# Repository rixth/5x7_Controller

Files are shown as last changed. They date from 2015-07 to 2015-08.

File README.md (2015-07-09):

# 5x7 Controller

This is a project that provides hardware & firmware for a small (43x70mm) board that contains four 5x7 row-anode LED matrices.

## Controller primary components

* 4 5x7 row-anode LED matrices
* 2 Texas Instruments TLC59284 sixteen-channel LED driver (constant-current sink)
* 1 CD4022B 8-output counter
* 1 74HC540 inverting buffer
* 7 IRLML5203 P-channel mosfets
* Freescale Kinetis MKL02Z32VFM4 Cortex M0+ MCU (32k flash)
* So. Many. Interfaces.

## Brief design overview

This display is drawn row-by-row. The row to be drawn is selected by the counter, which feeds it output through an inverting-buffer, then out to the P-channel mosfets. The columns are selected by the TLC59284 which are essentially shift registers that can sink considerable (configurable) current, so you can avoid having many current limiting resistors for the LEDs.

The Kinetis MCU will be responsible for drawing the display, and receiving commands from the main controller. I have exposed the MCU's i2c, SPI and UART lines to headers.

The raw inputs for the row/column selection have also been broken out to the left side of the board - 4 pins are required (shift clk, in, latch + counter clk). This can be reduced by 1 if a solder bridge is used to tie the clock of the counter to the latch of the shift register.

## Software overview

The software is still in the planning phases, but the rough plan is to use a slim RTOS like [AtomThreads](http://atomthreads.com/) to both keep the display refeshed and take input from the host controller over i2c, SPI or serial.

The MCU will have an ASCII character set preloaded - but the command set will also allow the host to toggle single LEDs, rows and columns.

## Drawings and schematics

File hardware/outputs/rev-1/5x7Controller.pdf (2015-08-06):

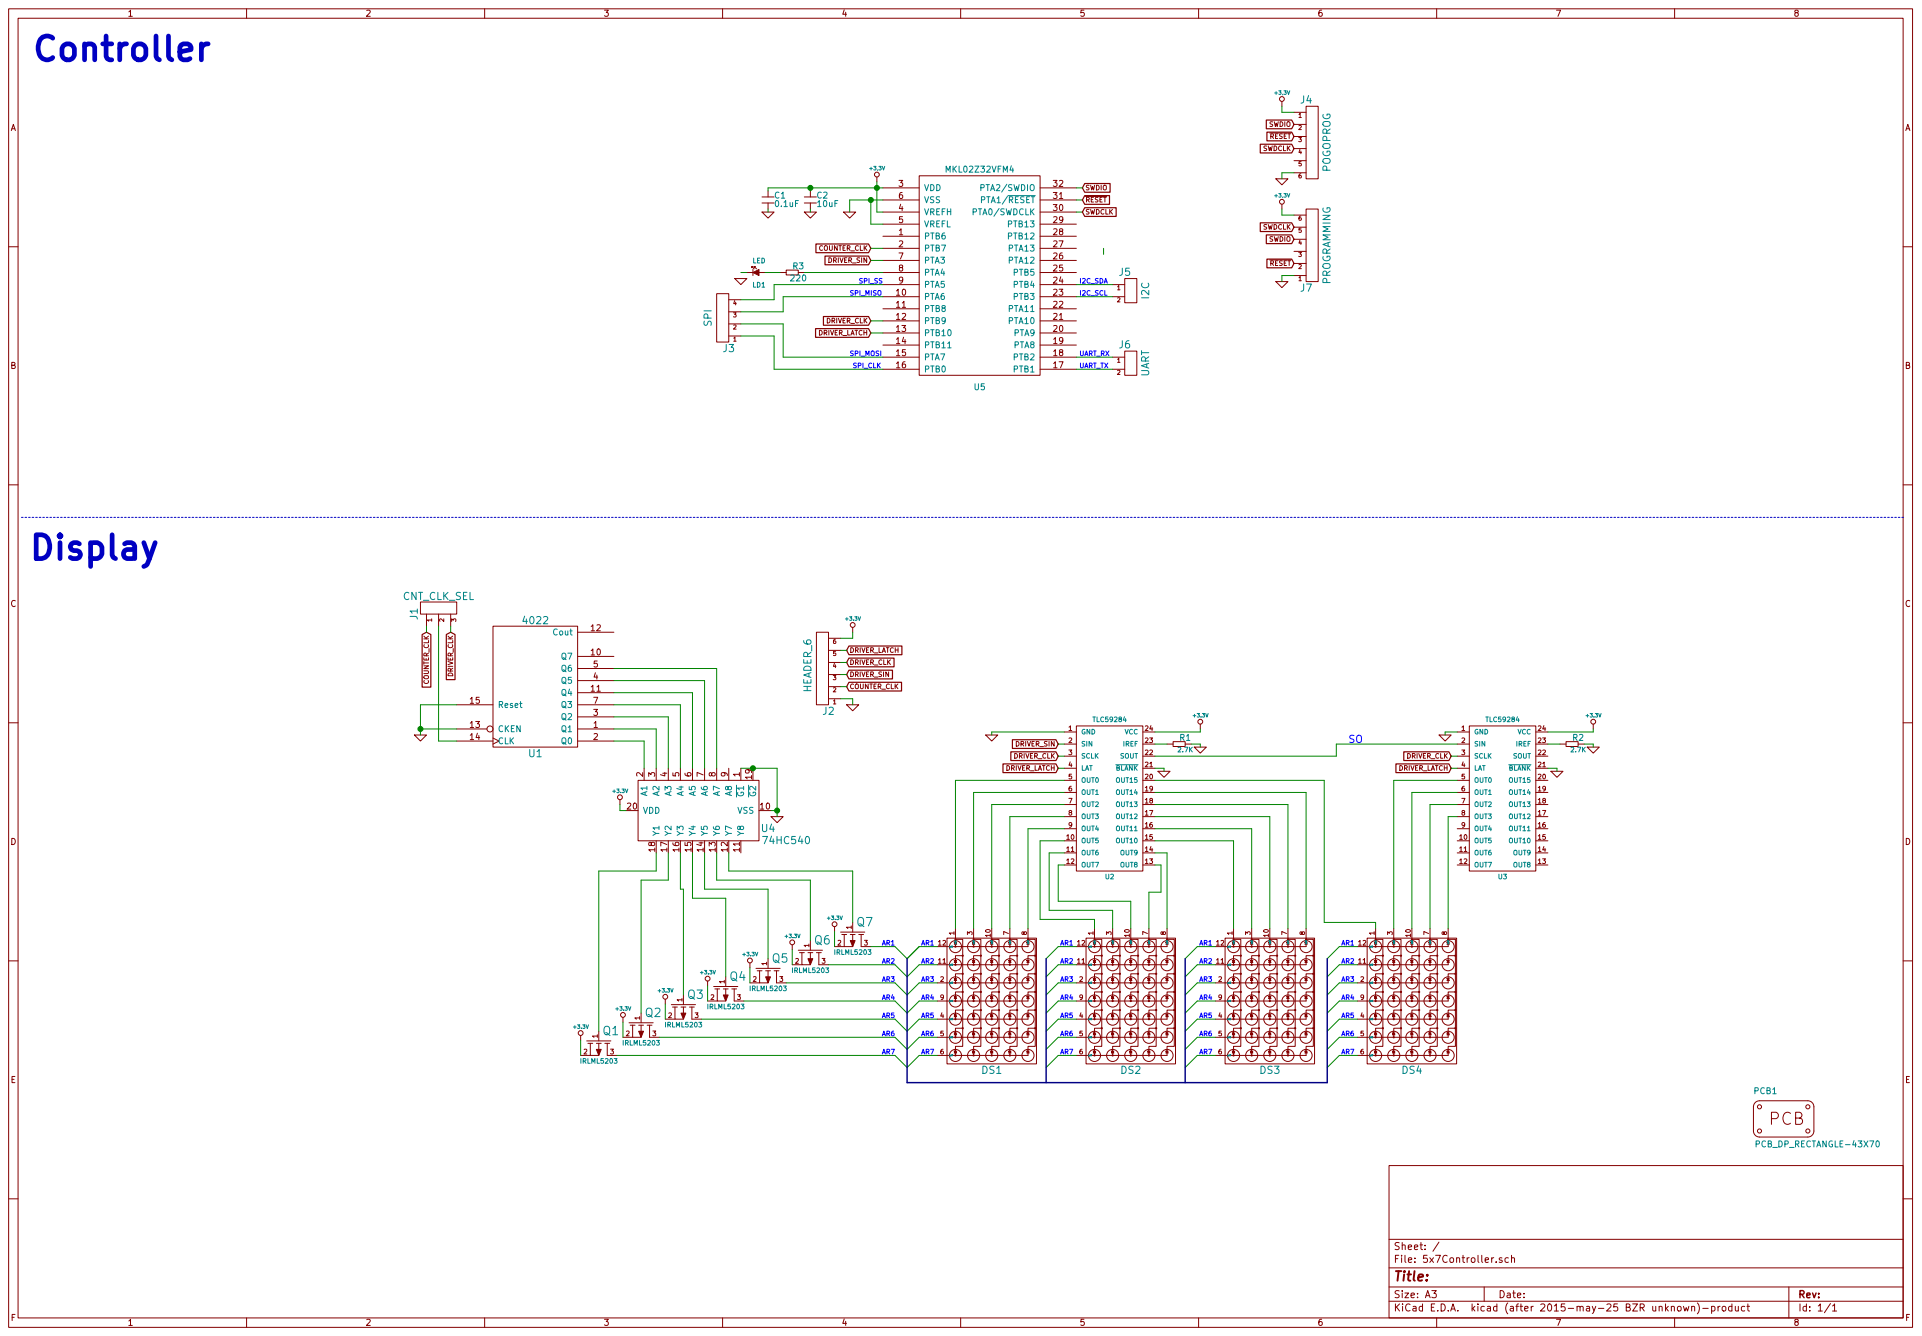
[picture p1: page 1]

Id: 1/1 Title: File: 5x7Controller.sch Sheet: / cc1 1

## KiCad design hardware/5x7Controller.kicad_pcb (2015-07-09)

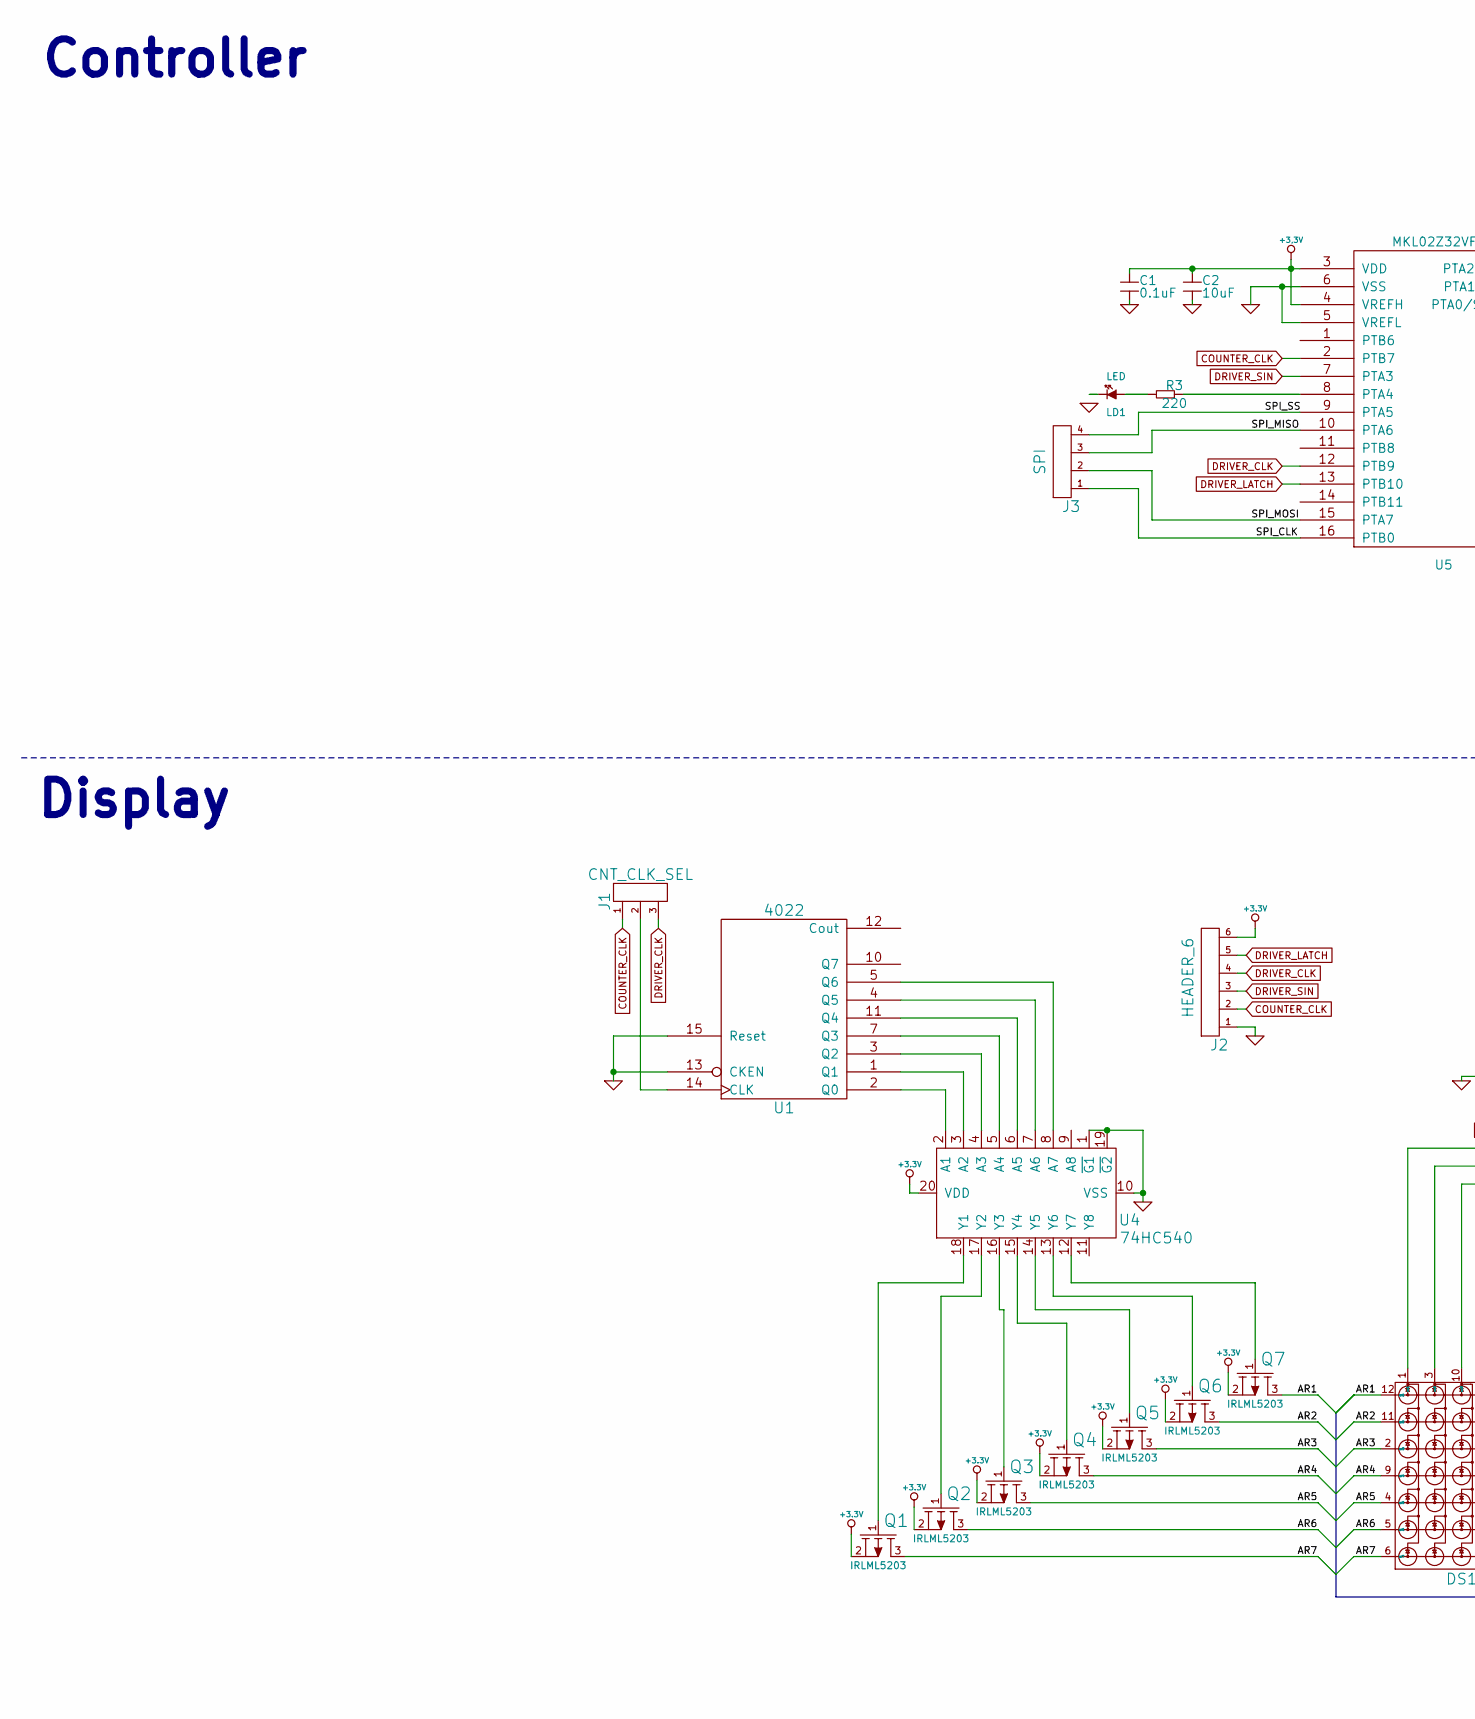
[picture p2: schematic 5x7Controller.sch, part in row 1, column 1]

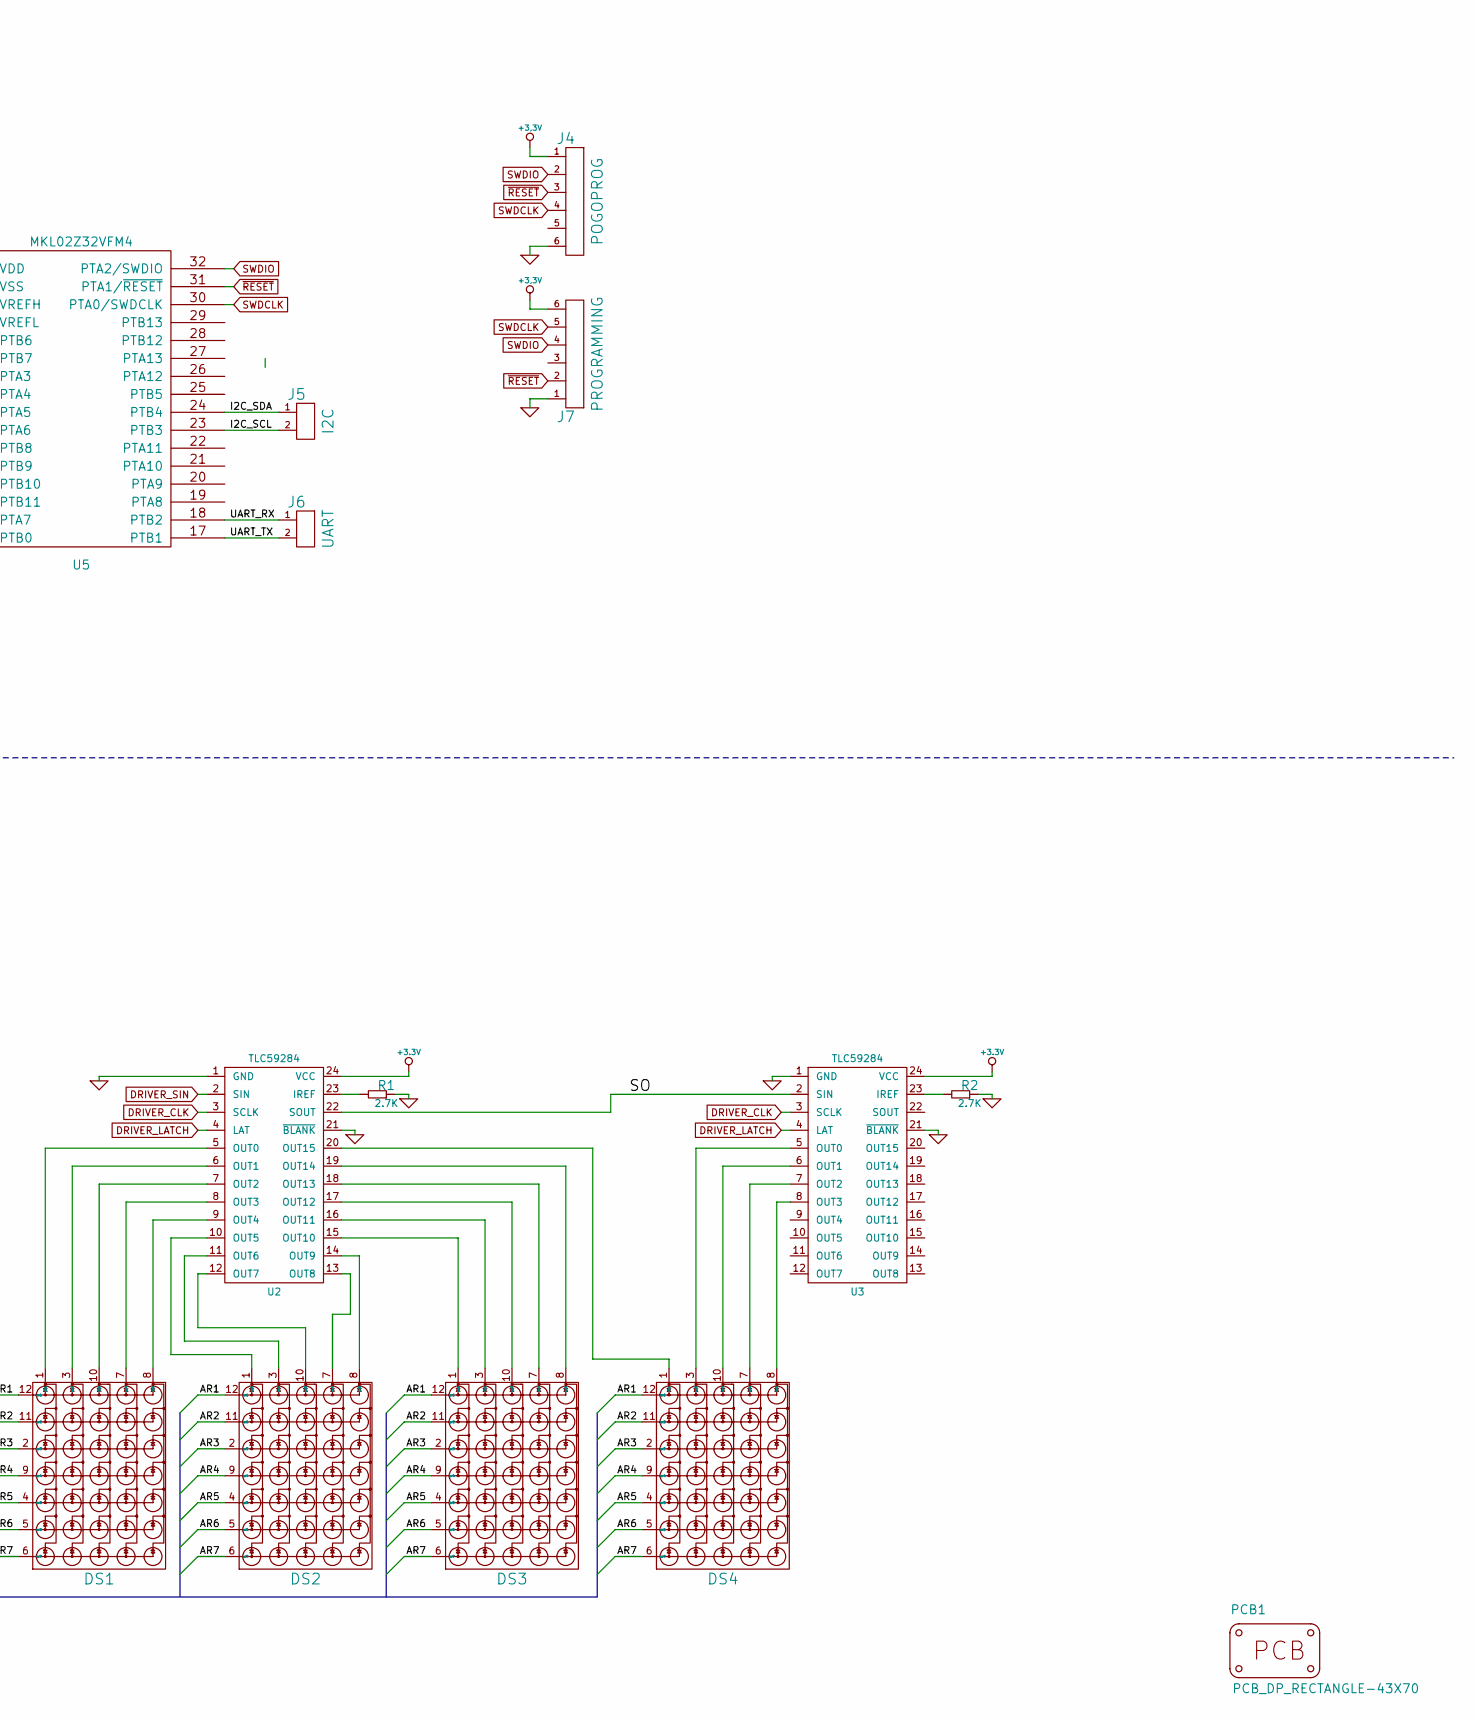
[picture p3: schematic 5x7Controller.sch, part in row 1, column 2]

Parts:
C1: 0.1uF; c_0603
C2: 10uF; c_0603
DS1, DS2, DS3, DS4: VAOM-C07573G9-BW/32; VAOM-A07573G9
J1: CNT_CLK_SEL; 3-way_bridge_0603
J2: HEADER_6; pin_strip_6
J3: SPI; pin_socket_4
J4: POGOPROG; POGOPROG-CONN-OH-SMALLERVIAS
J5: I2C; pin_socket_2
J6: UART; pin_socket_2
J7: PROGRAMMING; pin_strip_6
LD1: LED; Led_0603
PCB1: PCB_DP_RECTANGLE-43X70; dp_devices-DP7043_V1
Q1, Q2, Q3, Q4, Q5, Q6, Q7: IRLML5203; sot23
R1, R2: 2.7K; r_0603
R3: 220; r_0603
U1: 4022; tssop-16
U2, U3: TLC59284; ssop-24
U4: 74HC540; tssop-20
U5: MKL02Z32VFM4; QFN-32-1EP_5x5mm_Pitch0.5mm

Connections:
/AR1: DS1.12 (ar1), DS2.12 (ar1), DS3.12 (ar1), DS4.12 (ar1), Q7.3 (D)
/AR2: DS1.11 (ar2), DS2.11 (ar2), DS3.11 (ar2), DS4.11 (ar2), Q6.3 (D)
/AR3: DS1.2 (ar3), DS2.2 (ar3), DS3.2 (ar3), DS4.2 (ar3), Q5.3 (D)
/AR4: DS1.9 (ar4), DS2.9 (ar4), DS3.9 (ar4), DS4.9 (ar4), Q4.3 (D)
/AR5: DS1.4 (ar5), DS2.4 (ar5), DS3.4 (ar5), DS4.4 (ar5), Q3.3 (D)
/AR6: DS1.5 (ar6), DS2.5 (ar6), DS3.5 (ar6), DS4.5 (ar6), Q2.3 (D)
/AR7: DS1.6 (ar7), DS2.6 (ar7), DS3.6 (ar7), DS4.6 (ar7), Q1.3 (D)
/I2C_SCL: J5.2, U5.23 (PTB3)
/I2C_SDA: J5.1, U5.24 (PTB4)
/SO: U2.22 (SOUT), U3.2 (SIN)
/SPI_CLK: J3.1, U5.16 (PTB0)
/SPI_MISO: J3.3, U5.10 (PTA6)
/SPI_MOSI: J3.2, U5.15 (PTA7)
/SPI_SS: J3.4, U5.9 (PTA5)
/UART_RX: J6.1, U5.18 (PTB2)
/UART_TX: J6.2, U5.17 (PTB1)
COUNTER_CLK: J1.1, J2.2, U5.2 (PTB7)
DRIVER_CLK: J1.3, J2.4, U2.3 (SCLK), U3.3 (SCLK), U5.12 (PTB9)
DRIVER_LATCH: J2.5, U2.4 (LAT), U3.4 (LAT), U5.13 (PTB10)
DRIVER_SIN: J2.3, U2.2 (SIN), U5.7 (PTA3)
GND: C1.2, C2.2, J2.1, J4.6, J7.1, R1.1, R2.1, U1.13 (CKEN), U1.15 (Reset), U2.1 (GND), U2.21 (~BLANK), U3.1 (GND), U3.21 (~BLANK), U4.1 (~G1), U4.10 (VSS), U4.19 (~G2), U5.5 (VREFL), U5.6 (VSS)
unnamed: DS1.1 (cc1), U2.5 (OUT0)
unnamed: DS1.3 (cc2), U2.6 (OUT1)
unnamed: DS1.7 (cc4), U2.8 (OUT3)
unnamed: DS1.8 (cc5), U2.9 (OUT4)
unnamed: DS1.10 (cc3), U2.7 (OUT2)
unnamed: DS2.1 (cc1), U2.10 (OUT5)
unnamed: DS2.3 (cc2), U2.11 (OUT6)
unnamed: DS2.7 (cc4), U2.13 (OUT8)
unnamed: DS2.8 (cc5), U2.14 (OUT9)
unnamed: DS2.10 (cc3), U2.12 (OUT7)
unnamed: DS3.1 (cc1), U2.15 (OUT10)
unnamed: DS3.3 (cc2), U2.16 (OUT11)
unnamed: DS3.7 (cc4), U2.18 (OUT13)
unnamed: DS3.8 (cc5), U2.19 (OUT14)
unnamed: DS3.10 (cc3), U2.17 (OUT12)
unnamed: DS4.1 (cc1), U2.20 (OUT15)
unnamed: DS4.3 (cc2), U3.5 (OUT0)
unnamed: DS4.7 (cc4), U3.7 (OUT2)
unnamed: DS4.8 (cc5), U3.8 (OUT3)
unnamed: DS4.10 (cc3), U3.6 (OUT1)
unnamed: J1.2, U1.14 (CLK)
unnamed: LD1.1 (A), R3.2
unnamed: Q1.1 (G), U4.18 (Y1)
unnamed: Q2.1 (G), U4.17 (Y2)
unnamed: Q3.1 (G), U4.16 (Y3)
unnamed: Q4.1 (G), U4.15 (Y4)
unnamed: Q5.1 (G), U4.14 (Y5)
unnamed: Q6.1 (G), U4.13 (Y6)
unnamed: Q7.1 (G), U4.12 (Y7)
unnamed: R1.2, U2.23 (IREF)
unnamed: R2.2, U3.23 (IREF)
unnamed: R3.1, U5.8 (PTA4)
unnamed: U1.1 (Q1), U4.3 (A2)
unnamed: U1.2 (Q0), U4.2 (A1)
unnamed: U1.3 (Q2), U4.4 (A3)
unnamed: U1.4 (Q5), U4.7 (A6)
unnamed: U1.5 (Q6), U4.8 (A7)
unnamed: U1.7 (Q3), U4.5 (A4)
unnamed: U1.11 (Q4), U4.6 (A5)
SWDCLK: J4.4, J7.5, U5.30 (PTA0/SWDCLK)
SWDIO: J4.2, J7.4, U5.32 (PTA2/SWDIO)
~RESET: J4.3, J7.2, U5.31 (PTA1/~RESET)

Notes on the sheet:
Display
Controller

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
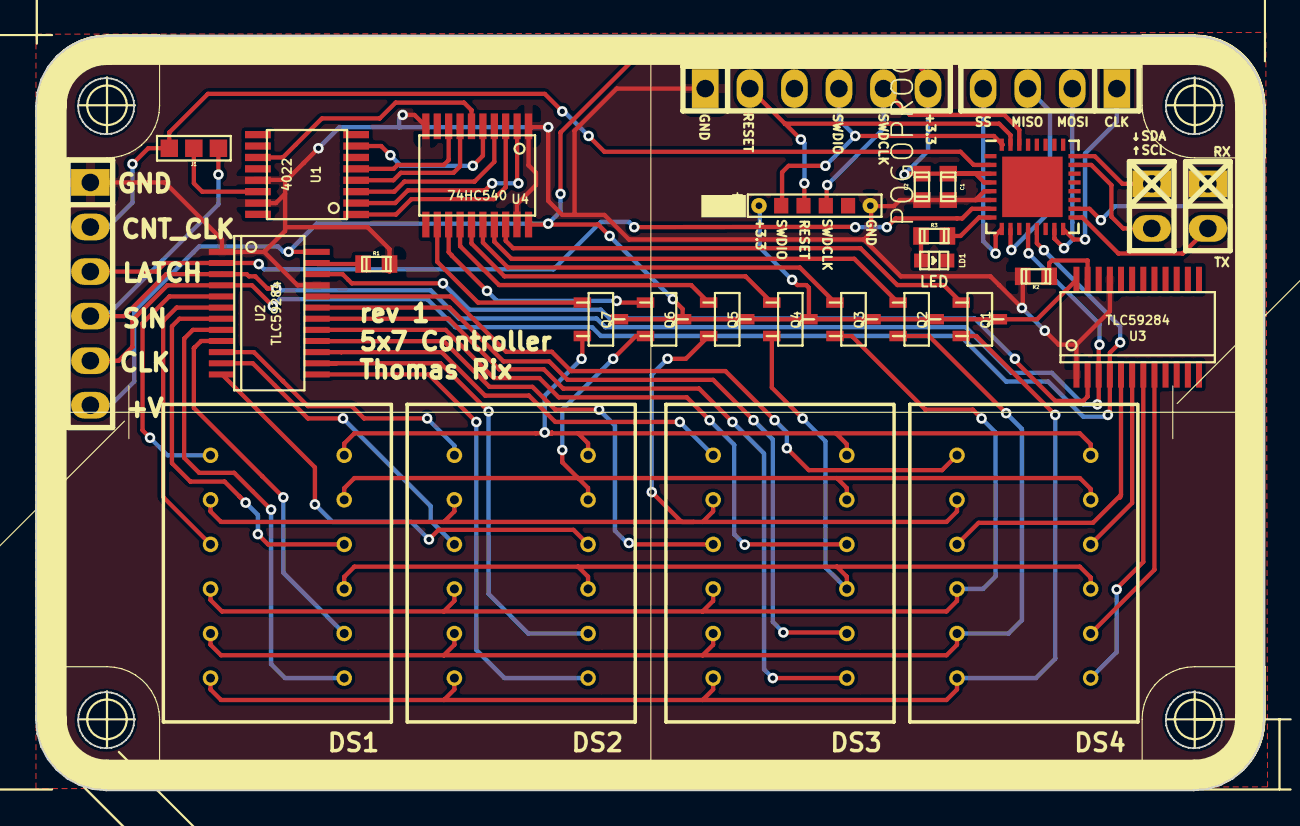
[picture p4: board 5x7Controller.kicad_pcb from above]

Board: 2 copper layers, 70.0 x 43.0 mm, 30 parts (0 on the bottom side), 64 nets.
